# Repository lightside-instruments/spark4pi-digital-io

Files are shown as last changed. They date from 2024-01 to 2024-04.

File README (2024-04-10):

spark4pi-* is a modular hardware platform for managed
instrument implementations controlled over Raspberry Pi
compatible 40 pin interface. The design is inspired by 
the Spark hardware platform for networking as form factor
but with a Raspberry Pi 40 pin connector as management
interface instead of 96boards.

The spark4pi-digital-io
has 6x SMA connectors connected to input (3.3V or 1.65V)
and output drivers (3.3V or 5V with open-circuit and 1.65V
or 2.5V with 50 ohm termination )
with configurable direction that are connected to GPIOs on the
Raspberry Pi connector. 2 GPIOs per channel one for selection of
direction and one for the actual signal.

The project includes the following components:
1. board - schematic and PCB design files for KiCAD
2. mechanical - technical documentation for production
 of a 1U 19 inch rack mountable ESD Acrylic box.
3. board-pi-bridge - design files for board that
 connects together a Pi compatible board with the instrument
 extension base board mounted to the left of the Pi compatible
 control board.

The project is published by Lightside Instruments AS
under TAPR Open Hardware License. Read the LICENSE file
for details.

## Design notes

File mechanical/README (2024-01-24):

Use 4mm acrylic sheets and laser cutter:

Blue  - Engrave (or make a pocket with CNC) 2 mm deep for the screw heads - all blue circles.
Cyan  - Engrave logo and port numbers with appropriate settings.
Red   - Cut.
Green - Cut. Add clearance fit tollerancesif needed  (openings are 4 mm) so it is your responsibily to use correct slack if you need to. 1 mm seems to be OK option.
Magenta - Cut. Ventilation holes.
Yellow - Informational. Board outlines. Ignore when cutting.

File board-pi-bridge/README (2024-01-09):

pi-bridge is an open hardware adapter board for connecting
Raspberry Pi to base board mounted at the same level
to the right side of the Pi board.

The initial release pi-bridge includes schematic and PCB
design files for KiCAD.

The project is published by Lightside Instruments AS
under TAPR Open Hardware License. Read the LICENSE file
for details.

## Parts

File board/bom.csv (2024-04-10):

Reference | Quantity | footprint | Value | Tolerance | Voltage | Current | Power | Mfr Part #
J101,J201,J301,J401,J601,J501 | 6 | SMA_LINX_CONSMA002_Horizontal | Conn_01x01_Shielded |  |  |  |  | CONSMA002-L
R2,R5 | 2 | R_0402_1005Metric | 5.1K |  |  |  |  | ERJ-2RKF5101X
U601,U101,U301,U501,U401 | 6 | TSOP-5_1.65x3.05mm_P0.95mm | 74LVC1G125 |  |  |  |  | 74LVC1G125GV,125
U102,U302,U502,U602,U202,U402 | 6 | SOT-363_SC-70-6 | TXU0101DCK |  |  |  |  | TXU0101DCK
D301,D101,D601,D501,D201,D401 | 6 | LED_0603_1608Metric | LED_GREEN |  |  |  |  | 150040VS73240
Q602,Q202,Q601,Q102,Q101,Q501,Q502,Q401,Q302,Q301,Q201,Q402 | 12 | SOT-323_SC-70 | Q_NPN_BEC_BRT |  |  |  |  | PDTC114EU,115
U403,U103,U203,U303,U603,U503 | 6 | SOT-23-5 | SN74LVC1G14DBV |  |  |  |  | SN74LVC1G14DBV
C401,C402,C302,C301,C101,C602,C502,C201,C601,C102,C202,C501,C104,C204,C304,C404,C504,C604 | 18 | C_0402_1005Metric | 100nF |  |  |  |  | 885012205037
D102,D302,D202,D502,D402,D602 | 6 | LED_0603_1608Metric | LED_BLUE |  |  |  |  | 150040VS73240
R504,R604,R304,R204,R404,R104 | 6 | R_0402_1005Metric | 10K |  |  |  |  | CRCW040210K0FKEDC
D103,D603,D403,D503,D303,D203 | 6 | R_0402_1005Metric | D_TVS |  |  |  |  | PESD0402-140
C2,C1,C3,C4 | 4 | C_0402_1005Metric | 10uF |  |  |  |  | ZRB15XR61A106ME01D
R203,R403,R603,R503,R303,R103 | 6 | R_0805_2012Metric | 51 |  |  |  |  | ERJ-P06J510V
D1 | 1 | LED_0603_1608Metric | LED_WHITE |  |  |  |  | 150060VS55040
R301,R401,R1,R502,R302,R101,R402,R602,R601,R501,R202,R201,R102 | 13 | R_0402_1005Metric | 1K |  |  |  |  | ERJ-2GEJ102X
P5 | 1 | PinHeader_2x20_P2.54mm_Vertical_1_04mm | Raspberry_Pi_2_3 |  |  |  |  | SSW-120-01-T-D-006
J3,J4 | 2 | PinHeader_1x03_P2.54mm_Vertical | Conn_01x03 |  |  |  |  | M20-9770346
J2 | 1 | PinHeader_2x01_P2.54mm_Vertical | Conn_01x02 |  |  |  |  | M20-9990246
U1 | 1 | SOT-223-3_TabPin2 | LD1117S33TR_SOT223 |  |  |  |  | LD1117S33TR
U2 | 1 | SOT-223-3_TabPin2 | LM317_SOT-223 |  |  |  |  | LM317DCY
J1 | 1 | USB_C_Receptacle_GCT_USB4105-xx-A_16P_TopMnt_Horizontal | USB_C_Receptacle_USB2.0 |  |  |  |  | USB4105-GF-A
R4 | 1 | R_0402_1005Metric | 68 |  |  |  |  | CR0402-FX-68R0GLF
R3 | 1 | R_0402_1005Metric | 220 |  |  |  |  | CR0402-FX-2200GLF

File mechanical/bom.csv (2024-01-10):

Reference | Quantity | Mfr | Mfr Part # | Description
M1 | 4 | Wurth | 971110154 | M2.5 Standoff 11mm_w_6mm_ext_thread
M2 | 14 | Wurth | 970060154 | M2.5 Standoff Female-Female 6mm
M3 | 24 | Wurth | SCR-PAN-D7985-4.8-A2K-M2,5X4-PH | M2.5 Screw 4mm
M4 | 6 | Wurth | 970110155 | Standoff Female-Female 11mm
M5 | 4 |  | DIN7985 M2,5x35 | Pan head screw M2.5 35mm

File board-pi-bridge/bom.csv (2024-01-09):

Reference | Quantity | Identifier | footprint | Value | Tolerance | Voltage | Current | Power | PN
J1 | 1 |  | pi-bridge:PinSocket_2x20_P2.54mm_Vertical_1_04mm | - |  |  |  |  | SSQ-120-03-F-D
J2 | 1 |  | pi-bridge:PinSocket_2x20_P2.54mm_Vertical_1_04mm | - |  |  |  |  | SSQ-120-03-F-D

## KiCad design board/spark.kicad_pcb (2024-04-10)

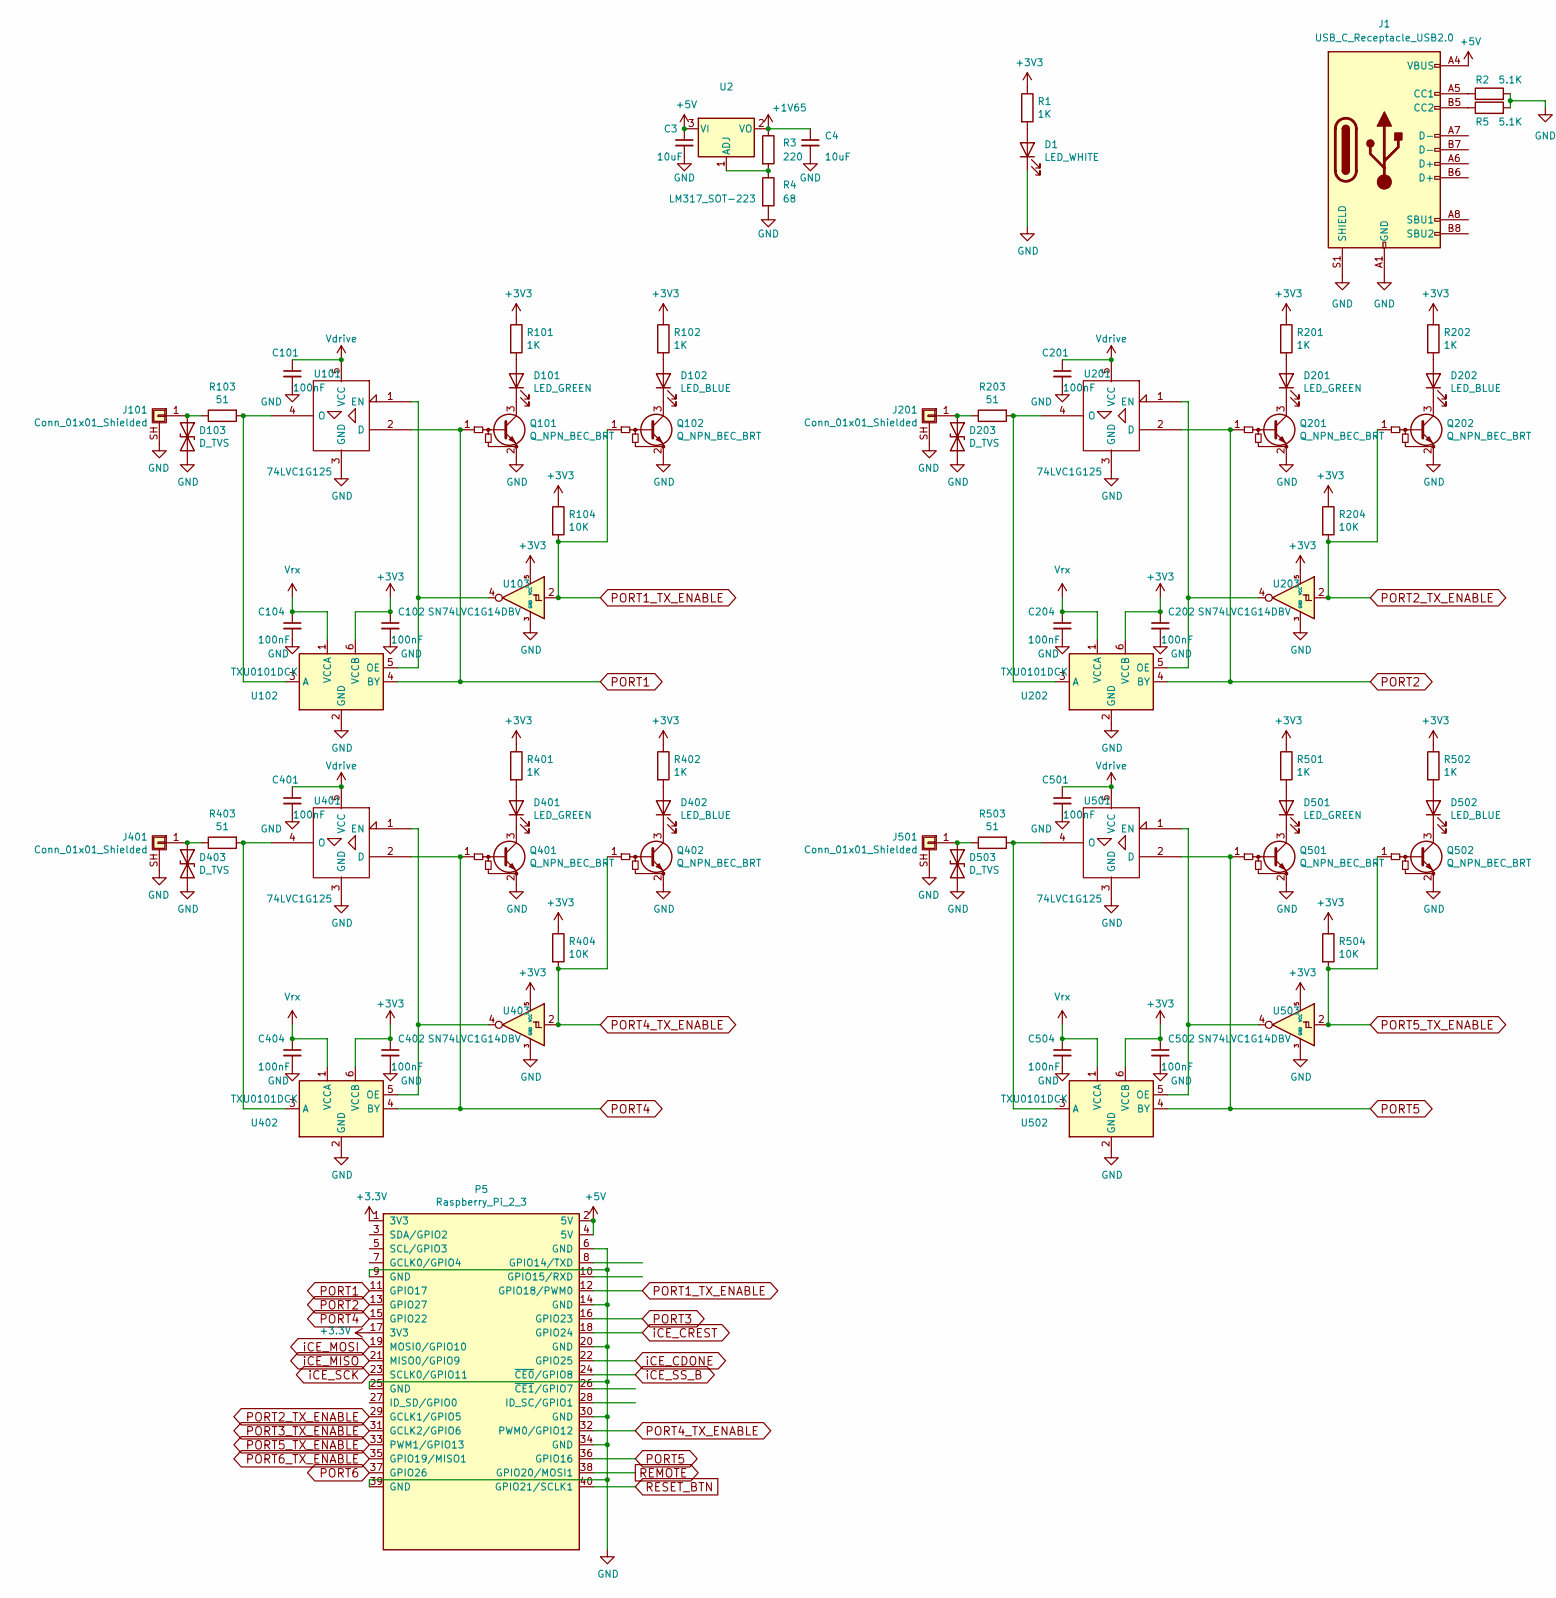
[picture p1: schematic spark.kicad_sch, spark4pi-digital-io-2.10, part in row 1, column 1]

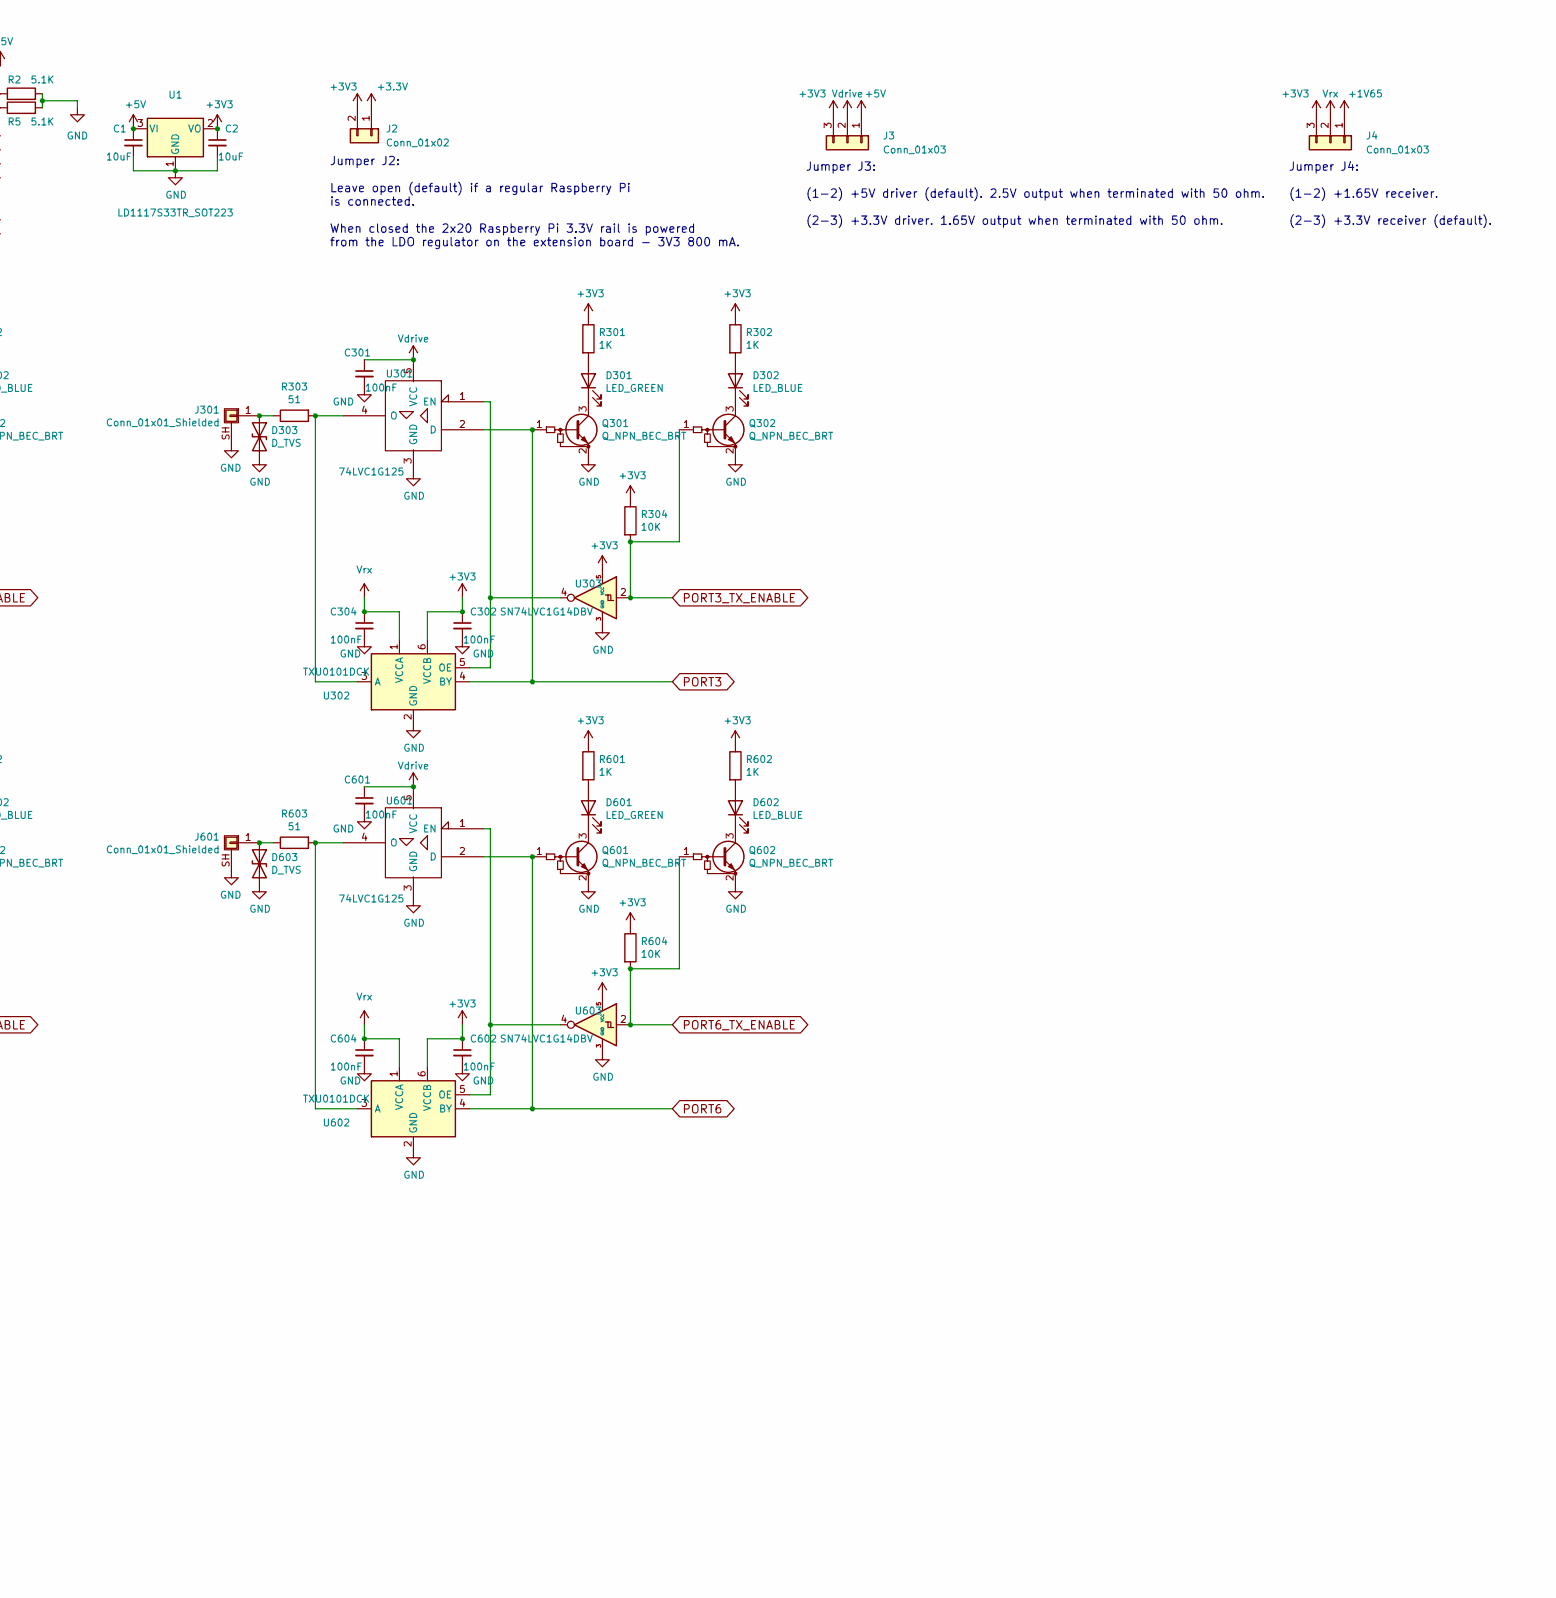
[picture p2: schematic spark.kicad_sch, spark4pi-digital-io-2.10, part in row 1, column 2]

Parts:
C1, C2, C3, C4: 10uF; C_0402_1005Metric
C101, C102, C104, C201, C202, C204, C301, C302, C304, C401, C402, C404, C501, C502, C504, C601, C602, C604: 100nF; C_0402_1005Metric
D1: LED_WHITE; LED_0603_1608Metric
D101, D201, D301, D401, D501, D601: LED_GREEN; LED_0603_1608Metric
D102, D202, D302, D402, D502, D602: LED_BLUE; LED_0603_1608Metric
D103, D203, D303, D403, D503, D603: D_TVS; R_0402_1005Metric
J1: USB_C_Receptacle_USB2.0; USB_C_Receptacle_GCT_USB4105-xx-A_16P_TopMnt_Horizontal
J2: Conn_01x02; PinHeader_2x01_P2.54mm_Vertical
J3, J4: Conn_01x03; PinHeader_1x03_P2.54mm_Vertical
J101, J201, J301, J401, J501, J601: Conn_01x01_Shielded; SMA_LINX_CONSMA002_Horizontal
P5: Raspberry_Pi_2_3; PinHeader_2x20_P2.54mm_Vertical_1_04mm
Q101, Q102, Q201, Q202, Q301, Q302, Q401, Q402, Q501, Q502, Q601, Q602: Q_NPN_BEC_BRT; SOT-323_SC-70
R1, R101, R102, R201, R202, R301, R302, R401, R402, R501, R502, R601, R602: 1K; R_0402_1005Metric
R2, R5: 5.1K; R_0402_1005Metric
R3: 220; R_0402_1005Metric
R4: 68; R_0402_1005Metric
R103, R203, R303, R403, R503, R603: 51; R_0805_2012Metric
R104, R204, R304, R404, R504, R604: 10K; R_0402_1005Metric
U1: LD1117S33TR_SOT223; SOT-223-3_TabPin2
U2: LM317_SOT-223; SOT-223-3_TabPin2
U101, U201, U301, U401, U501, U601: 74LVC1G125; TSOP-5_1.65x3.05mm_P0.95mm
U102, U202, U302, U402, U502, U602: TXU0101DCK; SOT-363_SC-70-6
U103, U203, U303, U403, U503, U603: SN74LVC1G14DBV; SOT-23-5

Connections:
+1V65: C4.1, J4.1, R3.1, U2.2 (VO)
+3.3V: J2.1, P5.1 (3V3), P5.17 (3V3)
+3V3: C2.1, C102.1, C202.1, C302.1, C402.1, C502.1, C602.1, J2.2, J3.3, J4.3, R1.1, R101.1, R102.1, R104.1, R201.1, R202.1, R204.1, R301.1, R302.1, R304.1, R401.1, R402.1, R404.1, R501.1, R502.1, R504.1, R601.1, R602.1, R604.1, U1.2 (VO), U102.6 (VCCB), U103.5 (VCC), U202.6 (VCCB), U203.5 (VCC), U302.6 (VCCB), U303.5 (VCC), U402.6 (VCCB), U403.5 (VCC), U502.6 (VCCB), U503.5 (VCC), U602.6 (VCCB), U603.5 (VCC)
+5V: C1.1, C3.1, J1.A4 (VBUS), J1.A9 (VBUS), J1.B4 (VBUS), J1.B9 (VBUS), J3.1, P5.2 (5V), P5.4 (5V), U1.3 (VI), U2.3 (VI)
GND: C1.2, C2.2, C3.2, C4.2, C101.2, C102.2, C104.2, C201.2, C202.2, C204.2, C301.2, C302.2, C304.2, C401.2, C402.2, C404.2, C501.2, C502.2, C504.2, C601.2, C602.2, C604.2, D1.1 (K), D103.2 (A2), D203.2 (A2), D303.2 (A2), D403.2 (A2), D503.2 (A2), D603.2 (A2), J1.A1 (GND), J1.A12 (GND), J1.B1 (GND), J1.B12 (GND), J1.S1 (SHIELD), J101.SH (Shield), J201.SH (Shield), J301.SH (Shield), J401.SH (Shield), J501.SH (Shield), J601.SH (Shield), P5.6 (GND), P5.9 (GND), P5.14 (GND), P5.20 (GND), P5.25 (GND), P5.30 (GND), P5.34 (GND), P5.39 (GND), Q101.2 (E), Q102.2 (E), Q201.2 (E), Q202.2 (E), Q301.2 (E), Q302.2 (E), Q401.2 (E), Q402.2 (E), Q501.2 (E), Q502.2 (E), Q601.2 (E), Q602.2 (E), R2.2, R4.2, R5.2, U1.1 (GND), U101.3 (GND), U102.2 (GND), U103.3 (GND), U201.3 (GND), U202.2 (GND), U203.3 (GND), U301.3 (GND), U302.2 (GND), U303.3 (GND), U401.3 (GND), U402.2 (GND), U403.3 (GND), U501.3 (GND), U502.2 (GND), U503.3 (GND), U601.3 (GND), U602.2 (GND), U603.3 (GND)
unnamed: D1.2 (A), R1.2
unnamed: D101.1 (K), Q101.3 (C)
unnamed: D101.2 (A), R101.2
unnamed: D102.1 (K), Q102.3 (C)
unnamed: D102.2 (A), R102.2
unnamed: D103.1 (A1), J101.1, R103.1
unnamed: D201.1 (K), Q201.3 (C)
unnamed: D201.2 (A), R201.2
unnamed: D202.1 (K), Q202.3 (C)
unnamed: D202.2 (A), R202.2
unnamed: D203.1 (A1), J201.1, R203.1
unnamed: D301.1 (K), Q301.3 (C)
unnamed: D301.2 (A), R301.2
unnamed: D302.1 (K), Q302.3 (C)
unnamed: D302.2 (A), R302.2
unnamed: D303.1 (A1), J301.1, R303.1
unnamed: D401.1 (K), Q401.3 (C)
unnamed: D401.2 (A), R401.2
unnamed: D402.1 (K), Q402.3 (C)
unnamed: D402.2 (A), R402.2
unnamed: D403.1 (A1), J401.1, R403.1
unnamed: D501.1 (K), Q501.3 (C)
unnamed: D501.2 (A), R501.2
unnamed: D502.1 (K), Q502.3 (C)
unnamed: D502.2 (A), R502.2
unnamed: D503.1 (A1), J501.1, R503.1
unnamed: D601.1 (K), Q601.3 (C)
unnamed: D601.2 (A), R601.2
unnamed: D602.1 (K), Q602.3 (C)
unnamed: D602.2 (A), R602.2
unnamed: D603.1 (A1), J601.1, R603.1
unnamed: J1.A5 (CC1), R2.1
unnamed: J1.B5 (CC2), R5.1
unnamed: R3.2, R4.1, U2.1 (ADJ)
unnamed: R103.2, U101.4 (O), U102.3 (A)
unnamed: R203.2, U201.4 (O), U202.3 (A)
unnamed: R303.2, U301.4 (O), U302.3 (A)
unnamed: R403.2, U401.4 (O), U402.3 (A)
unnamed: R503.2, U501.4 (O), U502.3 (A)
unnamed: R603.2, U601.4 (O), U602.3 (A)
unnamed: U101.1 (EN), U102.5 (OE), U103.4
unnamed: U201.1 (EN), U202.5 (OE), U203.4
unnamed: U301.1 (EN), U302.5 (OE), U303.4
unnamed: U401.1 (EN), U402.5 (OE), U403.4
unnamed: U501.1 (EN), U502.5 (OE), U503.4
unnamed: U601.1 (EN), U602.5 (OE), U603.4
PORT1: P5.11 (GPIO17), Q101.1 (B), U101.2 (D), U102.4 (BY)
PORT1_TX_ENABLE: P5.12 (GPIO18/PWM0), Q102.1 (B), R104.2, U103.2
PORT2: P5.13 (GPIO27), Q201.1 (B), U201.2 (D), U202.4 (BY)
PORT2_TX_ENABLE: P5.29 (GCLK1/GPIO5), Q202.1 (B), R204.2, U203.2
PORT3: P5.16 (GPIO23), Q301.1 (B), U301.2 (D), U302.4 (BY)
PORT3_TX_ENABLE: P5.31 (GCLK2/GPIO6), Q302.1 (B), R304.2, U303.2
PORT4: P5.15 (GPIO22), Q401.1 (B), U401.2 (D), U402.4 (BY)
PORT4_TX_ENABLE: P5.32 (PWM0/GPIO12), Q402.1 (B), R404.2, U403.2
PORT5: P5.36 (GPIO16), Q501.1 (B), U501.2 (D), U502.4 (BY)
PORT5_TX_ENABLE: P5.33 (PWM1/GPIO13), Q502.1 (B), R504.2, U503.2
PORT6: P5.37 (GPIO26), Q601.1 (B), U601.2 (D), U602.4 (BY)
PORT6_TX_ENABLE: P5.35 (GPIO19/MISO1), Q602.1 (B), R604.2, U603.2
REMOTE: P5.38 (GPIO20/MOSI1)
RESET_BTN: P5.40 (GPIO21/SCLK1)
Vdrive: C101.1, C201.1, C301.1, C401.1, C501.1, C601.1, J3.2, U101.5 (VCC), U201.5 (VCC), U301.5 (VCC), U401.5 (VCC), U501.5 (VCC), U601.5 (VCC)
Vrx: C104.1, C204.1, C304.1, C404.1, C504.1, C604.1, J4.2, U102.1 (VCCA), U202.1 (VCCA), U302.1 (VCCA), U402.1 (VCCA), U502.1 (VCCA), U602.1 (VCCA)
iCE_CDONE: P5.22 (GPIO25)
iCE_CREST: P5.18 (GPIO24)
iCE_MISO: P5.21 (MISO0/GPIO9)
iCE_MOSI: P5.19 (MOSI0/GPIO10)
iCE_SCK: P5.23 (SCLK0/GPIO11)
iCE_SS_B: P5.24 (~CE0/GPIO8)

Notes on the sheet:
Jumper J3: (1-2) +5V driver (default). 2.5V output when terminated with 50 ohm. (2-3) +3.3V driver. 1.65V output when terminated with 50 ohm.
Jumper J4: (1-2) +1.65V receiver. (2-3) +3.3V receiver (default).
Jumper J2: Leave open (default) if a regular Raspberry Pi is connected. When closed the 2x20 Raspberry Pi 3.3V rail is powered from the LDO regulator on the extension board - 3V3 800 mA.

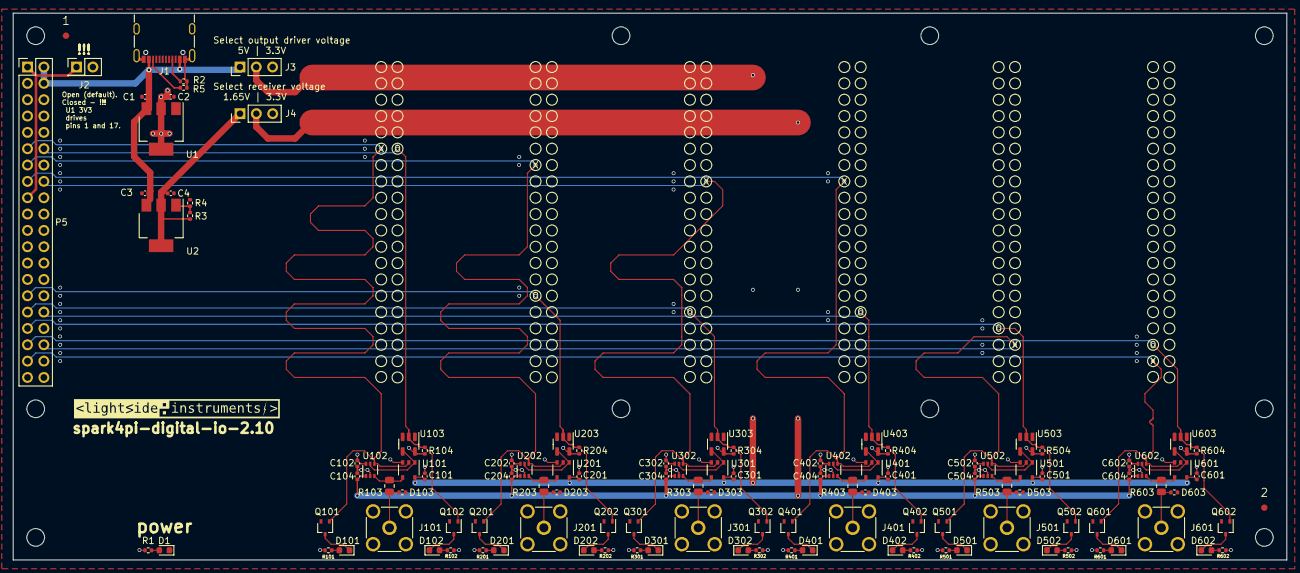
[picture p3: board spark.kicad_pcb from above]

Board: 4 copper layers, 198.0 x 85.0 mm, 121 parts (0 on the bottom side), 65 nets.

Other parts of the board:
1, 2: (no value)
Ref**: Val**; raspberry-pi-signal-interface-silks
Ref**#2, Ref**#3, Ref**#4, Ref**#5, Ref**#6: Val**; raspberry-pi-signal-interface-silks

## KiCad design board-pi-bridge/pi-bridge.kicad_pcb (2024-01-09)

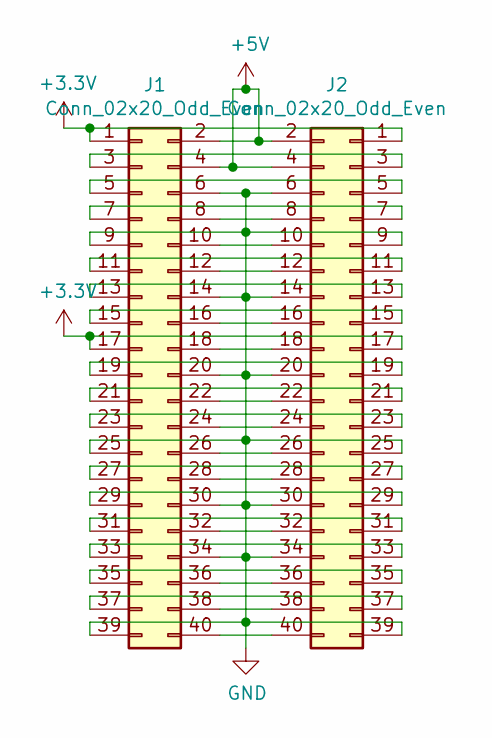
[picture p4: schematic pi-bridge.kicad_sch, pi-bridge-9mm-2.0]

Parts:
J1, J2: Conn_02x20_Odd_Even; PinSocket_2x20_P2.54mm_Vertical_1_04mm

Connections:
+3.3V: J1.1, J1.17, J2.1, J2.17
+5V: J1.2, J1.4, J2.2, J2.4
GND: J1.6, J1.9, J1.14, J1.20, J1.25, J1.30, J1.34, J1.39, J2.6, J2.9, J2.14, J2.20, J2.25, J2.30, J2.34, J2.39
unnamed: J1.3, J2.3
unnamed: J1.5, J2.5
unnamed: J1.7, J2.7
unnamed: J1.8, J2.8
unnamed: J1.10, J2.10
unnamed: J1.11, J2.11
unnamed: J1.12, J2.12
unnamed: J1.13, J2.13
unnamed: J1.15, J2.15
unnamed: J1.16, J2.16
unnamed: J1.18, J2.18
unnamed: J1.19, J2.19
unnamed: J1.21, J2.21
unnamed: J1.22, J2.22
unnamed: J1.23, J2.23
unnamed: J1.24, J2.24
unnamed: J1.26, J2.26
unnamed: J1.27, J2.27
unnamed: J1.28, J2.28
unnamed: J1.29, J2.29
unnamed: J1.31, J2.31
unnamed: J1.32, J2.32
unnamed: J1.33, J2.33
unnamed: J1.35, J2.35
unnamed: J1.36, J2.36
unnamed: J1.37, J2.37
unnamed: J1.38, J2.38
unnamed: J1.40, J2.40

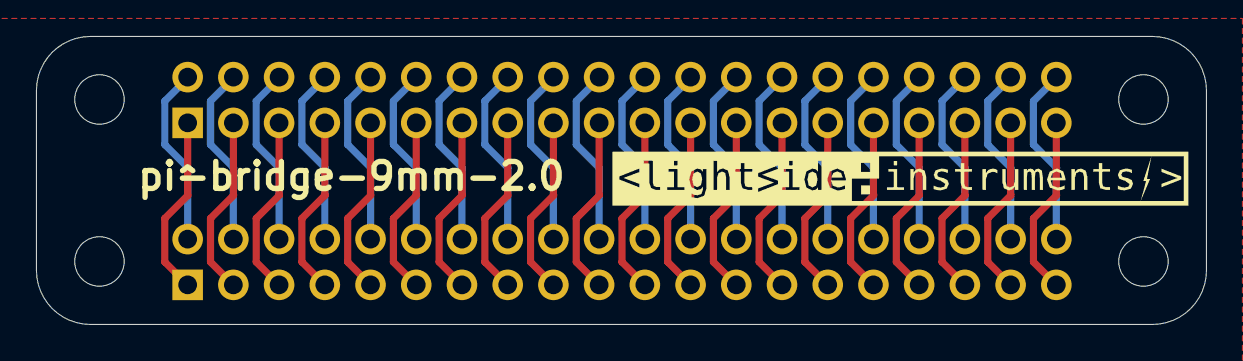
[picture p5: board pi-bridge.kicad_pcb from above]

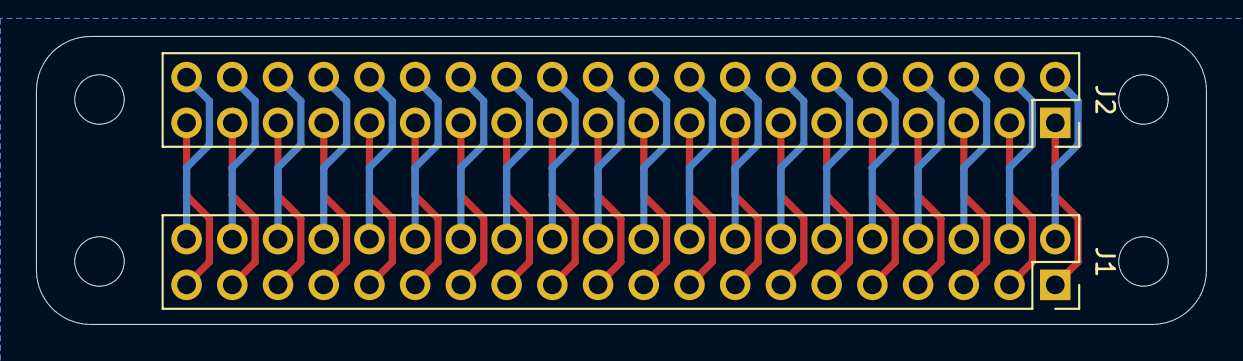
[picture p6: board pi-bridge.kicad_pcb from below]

Board: 4 copper layers, 65.0 x 16.0 mm, 3 parts (2 on the bottom side), 31 nets.

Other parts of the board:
svg2mod: G***; lsi-logo-32mm

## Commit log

2023-11-28 Release spark-relay-actuator-pi-3.0
    [powermod.kicad_pcb, powermod.sch, spark.kicad_pcb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]
2023-11-29 Release spark-relay-actuator-pi-3.1
    [spark.kicad_pcb, spark.kicad_sch]
2023-11-29 Release spark-relay-actuator-pi-3.2
    [spark.kicad_pcb, spark.kicad_sch]
2023-12-05 Release spark-relay-actuator-pi-3.3
2023-12-27 Release spark-relay-actuator-pi-3.4
    [bom.csv]
2024-01-08 Release spark4pi-relay-actuator-1.0
    [spark.kicad_pcb, spark.kicad_sch]
2024-01-09 Release spark4pi-relay-actuator-1.1
    [bom.csv, pi-bridge.kicad_pcb, pi-bridge.kicad_sch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]
2024-01-10 Release spark4pi-relay-actuator-1.2
    [bom.csv, powermod.kicad_pcb, powermod.kicad_sch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]
2024-01-11 Release spark4pi-relay-actuator-1.3
    [powermod-bom.csv, spark.kicad_pcb, spark.kicad_sch]
2024-01-20 Release spark4pi-relay-actuator-1.4
    [spark.kicad_pcb, spark.kicad_sch, spark_w_tstamp.kicad_pcb]
2024-01-24 Release spark4pi-relay-actuator-2.0
    [spark.kicad_pcb, spark.kicad_sch, spark_w_tstamp.kicad_pcb]
2024-02-01 Release spark4pi-relay-actuator-2.1
    [spark.kicad_pcb, spark.kicad_sch, spark_w_tstamp.kicad_pcb]
2024-02-02 Release spark4pi-relay-actuator-2.2
    [spark.kicad_pcb, spark.kicad_sch, spark_w_tstamp.kicad_pcb]
2024-02-04 Release spark4pi-relay-actuator-2.3
    [spark.kicad_pcb, spark.kicad_sch]
2024-02-07 Release spark4pi-digital-io-2.4
    [bom.csv, powermod.kicad_pcb, powermod.kicad_sch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]
2024-02-08 Release spark4pi-digital-io-2.5
    [spark.kicad_pcb, spark.kicad_sch]
2024-02-09 Release spark4pi-digital-io-2.6
    [spark.kicad_pcb, spark.kicad_sch]
2024-02-09 Release spark4pi-digital-io-2.7
    [spark.kicad_pcb, spark.kicad_sch]
2024-03-16 Release spark4pi-digital-io-2.8
    [bom.csv, spark.kicad_pcb, spark.kicad_sch]
2024-03-18 Release spark4pi-digital-io-2.9
    [spark.kicad_pcb, spark.kicad_sch]
2024-04-10 Release spark4pi-digital-io-2.10
    [bom.csv, spark.kicad_pcb, spark.kicad_sch]
